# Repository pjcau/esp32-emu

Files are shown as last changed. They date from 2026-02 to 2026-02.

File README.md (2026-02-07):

# ESP32-EMU - DIY Retro Gaming Console

> **[View Interactive 3D Models](https://pjcau.github.io/esp32-emu/)**

Personal project for building a retro gaming emulation console based on ESP32 WROVER, using the ESPlay Retro Emulation firmware.

## Overview

This project documents the build of a handheld console for emulating classic retro gaming systems, based on the ESPlay Micro hardware and the open source firmware by [pebri86](https://github.com/pebri86/esplay-retro-emulation).

## Supported Emulators

- **Nofrendo** - NES/Nintendo Emulator
- **GNUBoy** - GameBoy and GameBoy Color
- **SMSPlusGX** - Sega Master System, Game Gear and Coleco Vision
- **Atari** - Atari Systems
- **PC Engine** - NEC PC Engine/TurboGrafx
- **ZX-Spectrum** - Sinclair ZX Spectrum
- **MSX** - MSX Standard

> Note: Due to the 4MB Flash ROM, only 3 emulators can be preloaded at the same time.

## Additional Features

- In-game menu for all emulators
- Built-in audio player (WAV, MP3, OGG, FLAC)
- ESPlay Launcher with UGUI interface
- Built-in WiFi and Bluetooth 4 BLE

## Technical Specifications (ESPlay Micro)

| Component | Specification |
| --- | --- |
| Processor | ESP32 WROVER dual-core |
| Flash | 4MB built-in |
| PSRAM | 4MB built-in |
| Display | 2.4" ILI9341 TFT Panel |
| Audio DAC | UDA1334A I2S |
| Audio Jack | 3.5mm |
| Storage | microSD slot (SDMMC 1-line) |
| Charger | TP4056 Li-Po built-in |
| USB-Serial | CH340C |
| PCB Dimensions | 100 x 50 mm |
| Expansion Port | I2C |

## Bill of Materials

### 1. Main Board - ESPlay Micro
- **Product**: ESPlay Micro - DIY Console ESP32 WROVER
- **Price**: ~27 EUR
- **Link**: [AliExpress](https://it.aliexpress.com/item/1005010451380752.html)
- Includes: 1x ESPlay Micro, 1x USB Cable, 1x SD Card

### 2. LiPo Battery
- **Product**: 3.7V 5000mAh Lithium Polymer Battery (955565)
- **Price**: ~8 EUR
- **Link**: [AliExpress](https://it.aliexpress.com/item/1005008867815394.html)

### 3. MicroSD Card (optional, for additional ROMs)
- **Product**: SanDisk Ultra Micro SD (32GB/64GB/128GB)
- **Price**: ~1 EUR (32GB)
- **Link**: [AliExpress](https://it.aliexpress.com/item/1005007498167692.html)

### Total Hardware Cost: 35 EUR

## 3D Printed Case

Starting from the original "ESPlay Micro V2 Case" model by PierreGG, I developed a **custom V7 case** generated parametrically via Python + trimesh scripts, optimized for 3D printing.

- **Original model**: [Thingiverse - ESPlay Micro V2 Case](https://www.thingiverse.com/thing:5592683)
- **Custom V7 case**: `model_3d_cover_v1/scripts/build_v7.py` (automatic generation via Docker)
- **Output**: `model_3d_cover_v1/output/v7/` (STL for printing + GLB for viewing)

### V7 Case - Features

| Feature | Detail |
| --- | --- |
| Top shell | Solid top plate with precise cutouts for screen, D-pad (cross), buttons (round) |
| Bottom shell | Optimized depth (19.3mm), battery against inner wall |
| Screws | Countersunk M3 in the bottom, flush with the surface |
| Buttons | 1mm retention flange for snap-fit between board and top body |
| Ports | USB-C, audio jack, SD card slot, shoulder L/R |
| External dimensions | 103.3 x 58.3 x 27.3 mm |

### Closed Assembly

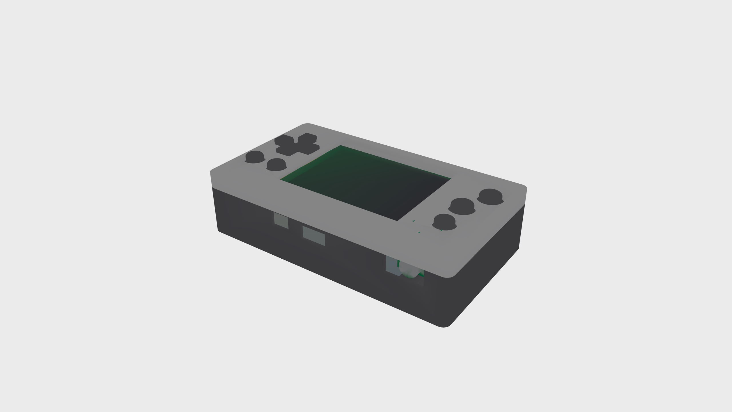
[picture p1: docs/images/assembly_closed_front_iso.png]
Closed assembly - isometric view


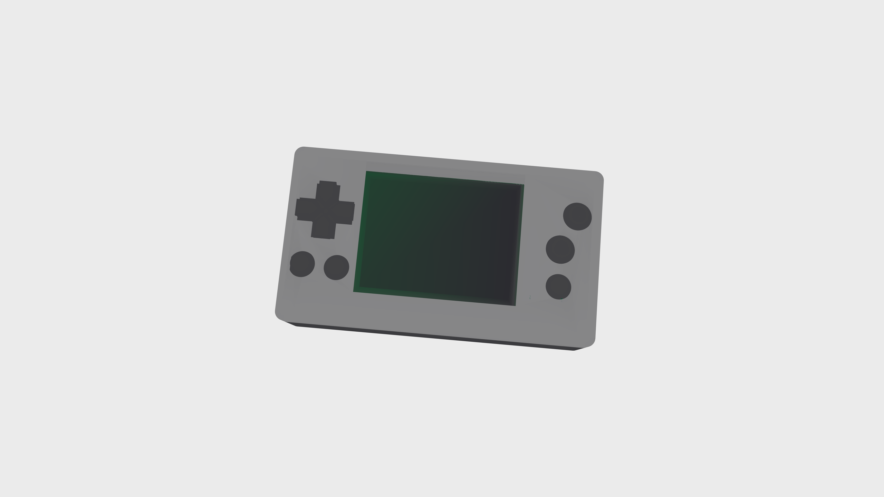
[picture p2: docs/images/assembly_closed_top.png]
Closed assembly - top view


### Exploded Assembly

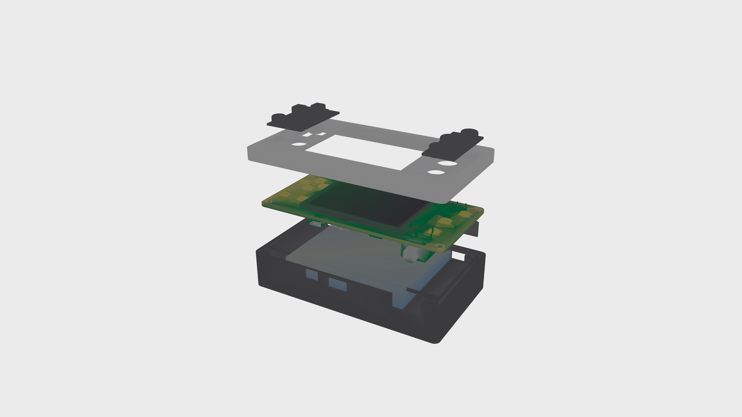
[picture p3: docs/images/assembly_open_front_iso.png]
Exploded assembly - isometric view


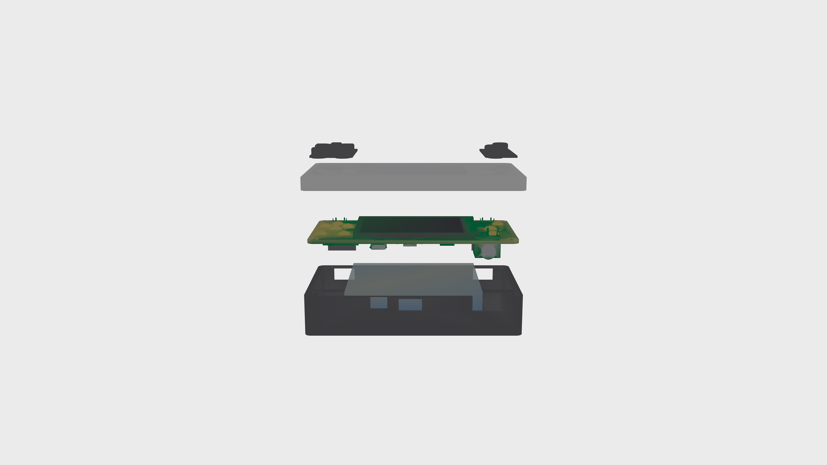
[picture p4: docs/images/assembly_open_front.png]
Exploded assembly - front view


### Top Body - Cutout Detail

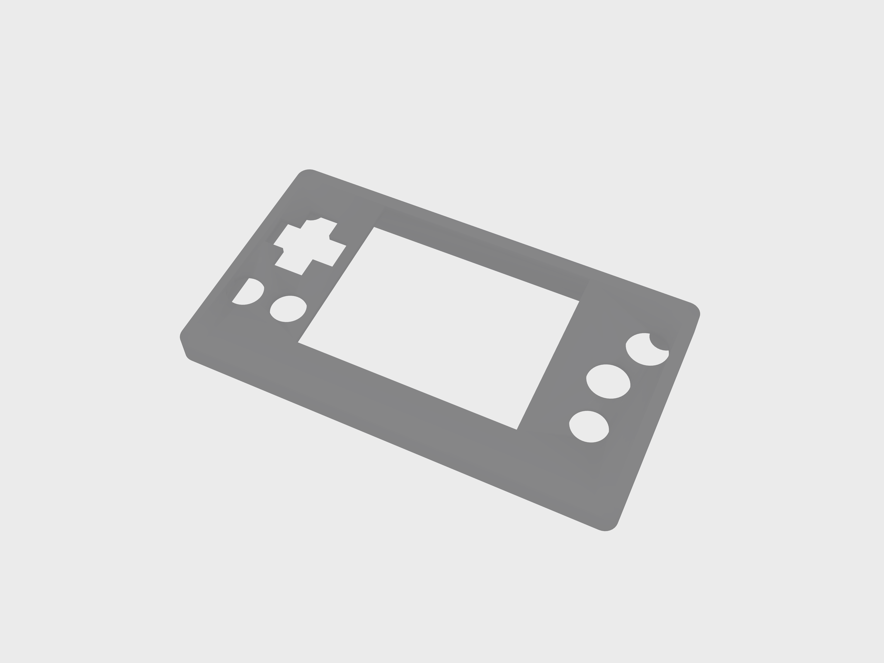
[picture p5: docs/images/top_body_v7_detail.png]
Top body V7 - detail


### How to Generate the Case

```bash
cd model_3d_cover_v1
docker compose run --rm cover-tool /workspace/scripts/build_v7.py
```

STL files for printing are generated in `output/v7/`:
- `top_body_v7.stl` - Top shell
- `bottom_body_v7.stl` - Bottom shell
- `btn_assy_1_v7.stl` - Left button assembly (D-pad + Start/Select)
- `btn_assy_2_v7.stl` - Right button assembly (A/B/X)
- `shoulder_l.stl` / `shoulder_r.stl` - Shoulder buttons

### 3D Printing

I used an **online 3D printing service** for manufacturing the case.

- **Printing cost**: 30 EUR
- Includes all necessary parts for the case

### Required Materials for the Case
- 4x M3 15mm screws
- Screen protector (optional): laser-cut 3mm acrylic (SVG file included)

## Cost Summary

| Item | Cost |
| --- | --- |
| Hardware (ESPlay + Battery + SD)  | 35 EUR |
| 3D Printed Case | 30 EUR |
| **Total Project Cost** | **65 EUR** |

## Resources and Useful Links

| Resource | Link |
| --- | --- |
| ESPlay Firmware | [GitHub - pebri86/esplay-retro-emulation](https://github.com/pebri86/esplay-retro-emulation) |
| Official Documentation | [Makerfabs - ESPlay Micro](https://www.makerfabs.com/esplay-micro.html) |
| 3D Case | [Thingiverse - ESPlay Micro V2 Case](https://www.thingiverse.com/thing:5592683) |

## Firmware Build Instructions

### Requirements
- ESP-IDF v3.3
- FFmpeg installed and in PATH

### Procedure
1. Clone the repository: `git clone https://github.com/pebri86/esplay-retro-emulation.git`
2. Edit `mkrelease.sh` with the correct paths
3. Run `./mkrelease.sh` to generate `esplay-retro-emu.fw`
4. Copy the file to `esplay/firmware/` on the SD card
5. Boot the console while holding the B button (bootloader mode)
6. Flash the firmware from the menu

## Assembly Instructions

1. Solder the LiPo battery to the ESPlay Micro board connectors
2. Insert the microSD card with the ROMs
3. 3D print the case
4. Assemble everything with the M3 screws
5. (Optional) Apply the acrylic screen protector

## SD Card Directory Structure

```
/
├── esplay/
│   └── firmware/
│       └── esplay-retro-emu.fw
├── roms/
│   ├── nes/
│   ├── gb/
│   ├── gbc/
│   ├── sms/
│   └── gg/
└── music/
    └── (WAV, MP3, OGG, FLAC files)
```

## Legal Notes

- The ESPlay firmware is released under the MIT License
- Only use ROMs for games you legally own
- The 3D case is released under the Creative Commons BY 4.0 License

## TODO

- [x] Order components
- [x] 3D print the case
- [ ] Assemble the hardware
- [ ] Flash the firmware
- [ ] Test the emulators
- [ ] Document the process with photos

---

*Project based on the work of [Fuji Pebri](https://github.com/pebri86) and the ESPlay community.*

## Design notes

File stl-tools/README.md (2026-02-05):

# STL Processing Tools

Tools for analyzing and fixing STL files for 3D printing, ensuring minimum wall thickness requirements are met while preserving part alignment for assembly.

## Requirements

- Docker
- Docker Compose

## Quick Start

```bash
cd stl-tools

# Run complete pipeline (recommended)
./run.sh pipeline

# Or run everything including renders and animations
./run.sh all
```

## Features

1. **Wall Thickness Analysis**: Checks all STL files for wall thickness < 1mm
2. **Automatic Fix**: Thickens thin walls while preserving part centers
3. **Assembly Verification**: Ensures parts still fit together after fixes
4. **Render Comparison**: Before/after visual comparisons
5. **Assembly Simulation**: Animated assembly/disassembly views
6. **Hardware Verification**: Checks alignment with PCB, screw holes, etc.

## Commands

| Command | Description |
|---|---|
| `./run.sh analyze` | Analyze STL files only |
| `./run.sh fix` | Fix wall thickness issues |
| `./run.sh verify` | Verify parts fit together |
| `./run.sh render` | Generate render comparisons |
| `./run.sh simulate` | Generate assembly animations |
| `./run.sh hardware` | Verify hardware alignment |
| `./run.sh pipeline` | Run complete pipeline |
| `./run.sh all` | Run everything |
| `./run.sh clean` | Remove output files |
| `./run.sh shell` | Open container shell |

## Output Files

After running the pipeline, check these output files:

```
output/
├── analysis_report.json       # Initial thickness analysis
├── analysis_summary.txt       # Human-readable analysis summary
├── fixed/                     # Fixed STL files
│   ├── frame.stl
│   ├── top_cover.stl
│   └── ...
├── fix_report.json            # Fix operation results
├── verification_report.json   # Assembly fit verification
├── pipeline_report.html       # Complete HTML report
├── renders/                   # Render images
│   ├── render_report.html
│   └── *.png
├── simulation/                # Animation files
│   ├── simulation_viewer.html
│   ├── assembly.gif
│   ├── disassembly.gif
│   └── rotation_*.gif
└── hardware_verification_report.json
```

## Configuration

Environment variables in `docker-compose.yml`:

| Variable | Default | Description |
|---|---|---|
| `MIN_WALL_THICKNESS` | `1.0` | Minimum wall thickness in mm |
| `PRESERVE_CENTERS` | `true` | Keep part centers invariant during fix |
| `FIX_METHOD` | `auto` | Fix method: auto, vertex, shell, pymeshlab |
| `NUM_SAMPLES` | `15000` | Samples for thickness analysis |

## How It Works

### Wall Thickness Analysis
Uses ray casting from surface points inward to measure the distance to the opposite surface. This gives an accurate measurement of wall thickness at thousands of sample points.

### Thickness Fix Algorithm
1. Identifies thin regions (< 1mm)
2. Calculates required offset for each vertex
3. Displaces vertices outward along normals
4. Translates mesh to preserve original centroid
5. Verifies fix meets requirements

### Center Preservation
After any mesh modification, the centroid is calculated and the mesh is translated to match the original centroid position. This ensures parts remain properly aligned in the assembly.

### Assembly Verification
Uses collision detection between all part pairs to ensure no unwanted intersections occur after thickness fixes.

## Input Files

The pipeline expects STL files in:
```
model3d/ESPlay micro v2 case - 5592683/files/
```

Expected files:
- `frame.stl` - Main case frame
- `top_cover.stl` - Front cover
- `back_cover.stl` - Back cover
- `d_Pad.stl` - D-pad
- `A_B.stl` - A/B buttons
- `L_R.stl` - Shoulder buttons
- `start_select.stl` - Start/Select buttons
- `menu.stl` - Menu button
- `power.stl` - Power button

## Troubleshooting

### Rendering fails
The container uses OSMesa for headless rendering. If renders are blank, check:
```bash
./run.sh shell
python -c "import trimesh; print(trimesh.viewer)"
```

### Fix doesn't meet thickness requirement
Try different fix methods:
```bash
# Edit docker-compose.yml
environment:
  - FIX_METHOD=shell  # or 'vertex' or 'pymeshlab'
```

### Parts don't fit after fix
If assembly verification fails, the fix may have been too aggressive. Reduce the offset or use a different method.

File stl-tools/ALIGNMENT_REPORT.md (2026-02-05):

# ESPlay Micro - Alignment Analysis Report

**Data**: 2026-02-04
**Progetto**: ESP32-EMU Console Retro Gaming

---

## 1. Coordinate System Analysis

### STL Case Orientation
Il case STL utilizza un sistema di coordinate dove:
- **X positivo** = lato destro della console
- **X negativo** = lato sinistro della console
- **Y** = INVERTITO rispetto al PCB

### PCB Orientation (Eagle)
- **X positivo** = lato destro (dove sono A/B, Menu)
- **X negativo** = lato sinistro (dove sono D-Pad, Start/Select)
- **Y positivo** = lato superiore (dove sono L/R shoulders)
- **Y negativo** = lato inferiore (USB, Audio)

### Trasformazione Applicata
Y-axis invertito per allineare i sistemi di coordinate.

---

## 2. Button Positions Comparison

| Componente | STL Center (X, Y) | PCB Center (X, Y) | Offset (mm) | Status |
|---|---|---|---|---|
| d_Pad | (-39.1, 5.5) | (-39.1, 8.0) | 2.5 | ✓ OK |
| A_B | (39.4, -3.8) | (41.5, 7.6) | 11.6 | ⚠ Offset |
| start_select | (-39.2, -12.0) | (-39.1, -10.4) | 1.5 | ✓ OK |
| menu | (41.5, 14.0) | (39.0, -10.5) | 24.7 | ⚠ Offset |
| power | (-4.7, -0.6) | (18.6, 10.6) | 25.8 | ⚠ Offset |

### L/R Shoulders (caso speciale)
- STL L_R è un **pezzo singolo** posizionato sul lato destro (X=42.0)
- PCB ha L_BTN (X=-38.6) e R_BTN (X=38.9) separati
- **Nota**: Il pezzo L_R potrebbe necessitare di essere specchiato per il lato sinistro

---

## 3. Layout Console

```
      L_BTN                              R_BTN
   ┌─────────────────────────────────────────────┐
   │                                             │
   │  ┌─────┐                        ┌───┐       │
   │  │D-Pad│        ┌──────┐        │A/B│       │
   │  └─────┘        │ LCD  │        └───┘       │
   │                 │Screen│                    │
   │  ┌──────────┐   └──────┘        ┌────┐      │
   │  │Start/Sel │                   │Menu│      │
   │  └──────────┘                   └────┘      │
   │                                             │
   └─────────────────────────────────────────────┘
           USB              AUDIO
```

---

## 4. Dimensional Compatibility

| Componente | Dimensioni (mm) |
|---|---|
| PCB | 100.0 x 50.0 x 1.6 |
| Top Cover | 110.7 x 55.7 x 10.0 |
| Back Cover | 110.0 x 55.0 x 11.0 |

**Margine Case-PCB**: ~5mm per lato (adeguato per montaggio)

---

## 5. Render Files

I seguenti file sono stati generati in `stl-tools/output/renders/`:

| File | Descrizione |
|---|---|
| assembly_colored.glb | Assembly completo con PCB e case |
| assembly_exploded.glb | Vista esplosa dei componenti |
| pcb_detailed.glb | PCB con marker posizioni bottoni |
| case_only.glb | Solo case senza PCB |
| viewer.html | Viewer 3D interattivo |

### Visualizzazione
```bash
# Avviare server e aprire viewer
python3 -m http.server 8082 --directory stl-tools/output/renders
# Poi aprire: http://localhost:8082/viewer.html
```

---

## 6. Conclusioni

### Compatibilità
- ✓ Dimensioni case compatibili con PCB 100x50mm
- ✓ Posizioni X dei bottoni allineate
- ⚠ Y-axis invertito - compensato nei render

### Note
- Il pezzo L_R è singolo e posizionato a destra; verificare se serve specchiatura
- Gli offset residui sono dovuti a differenze di design tra case Thingiverse e PCB ESPlay

---

*Report generato automaticamente - ESP32-EMU Project*

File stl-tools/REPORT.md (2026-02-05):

# ESPlay Micro - Report Analisi e Fix STL

**Data**: 2026-02-04
**Progetto**: ESP32-EMU Console Retro Gaming

---

## 1. Panoramica

Questo report documenta l'analisi, la correzione e la verifica dei file STL per il case ESPlay Micro V2, inclusa la compatibilità con il PCB originale.

### Obiettivi
1. Verificare che tutti i pezzi STL abbiano spessore minimo >= 1.0mm per la stampa 3D
2. Preservare i centroidi originali (nessun drift)
3. Mantenere dimensioni controllate (minimo aumento)
4. Verificare compatibilità con PCB ESPlay Micro (100x50mm)

---

## 2. File Sorgente

### PCB (da esplay_micro_hardware)
- **Repository**: https://github.com/pebri86/esplay_micro_hardware
- **File**: `new_esplay.brd` (Eagle format)
- **Dimensioni**: 100.0 x 50.0 x 1.6 mm
- **Fori montaggio**: 4 (M3, agli angoli)

### Case STL (da Thingiverse)
- **Sorgente**: ESPlay Micro V2 Case (Thing:5592683)
- **File originali**: 9 pezzi STL
- **Directory**: `model3d/ESPlay micro v2 case - 5592683/files/`

---

## 3. Analisi Spessore Originale

| Pezzo | Dimensioni Originali | Spessore (P5) | Stato |
|---|---|---|---|
| A_B | 8.7 x 21.5 x 4.2 mm | 0.20 mm | ❌ Troppo sottile |
| L_R | 16.0 x 5.0 x 9.0 mm | 0.20 mm | ❌ Troppo sottile |
| d_Pad | 20.8 x 20.8 x 4.2 mm | 0.20 mm | ❌ Troppo sottile |
| menu | 10.6 x 10.6 x 4.2 mm | 0.20 mm | ❌ Troppo sottile |
| power | 15.0 x 2.5 x 5.0 mm | 0.20 mm | ❌ Troppo sottile |
| start_select | 20.6 x 8.8 x 4.2 mm | 0.20 mm | ❌ Troppo sottile |
| frame | 54.6 x 42.2 x 4.5 mm | 0.49 mm | ❌ Troppo sottile |
| top_cover | 110.0 x 55.0 x 9.4 mm | 0.50 mm | ❌ Troppo sottile |
| back_cover | 110.0 x 55.0 x 11.0 mm | 3.30 mm | ✅ OK |

**Problema**: 8 su 9 pezzi hanno spessore < 1.0mm

---

## 4. Metodo di Fix Applicato

### Approccio: Vertex Normal Offset
- Offset dei vertici lungo le normali
- Preservazione del centroide tramite ri-centramento
- Offset differenziato per tipo di pezzo

### Parametri
| Tipo | Offset Applicato |
|---|---|
| Bottoni (A_B, d_Pad, menu, power, start_select, L_R) | 0.6 mm |
| Struttura (frame, top_cover) | 0.35 mm |
| back_cover | 0 mm (già OK) |

---

## 5. Risultati Fix

### Dimensioni Finali

| Pezzo | Originale | Fixed | Incremento |
|---|---|---|---|
| A_B | 8.7 x 21.5 x 4.2 | 9.8 x 22.4 x 5.4 | +1.1 x 0.9 x 1.2 |
| L_R | 16.0 x 5.0 x 9.0 | 16.9 x 6.2 x 10.1 | +0.9 x 1.2 x 1.1 |
| d_Pad | 20.8 x 20.8 x 4.2 | 21.7 x 21.8 x 5.4 | +0.9 x 1.0 x 1.2 |
| menu | 10.6 x 10.6 x 4.2 | 11.6 x 11.6 x 5.4 | +1.0 x 1.0 x 1.2 |
| power | 15.0 x 2.5 x 5.0 | 16.1 x 3.5 x 6.1 | +1.1 x 1.0 x 1.1 |
| start_select | 20.6 x 8.8 x 4.2 | 21.6 x 9.9 x 5.4 | +1.0 x 1.1 x 1.2 |
| frame | 54.6 x 42.2 x 4.5 | 55.0 x 42.6 x 5.0 | +0.4 x 0.4 x 0.5 |
| top_cover | 110.0 x 55.0 x 9.4 | 110.7 x 55.7 x 10.0 | +0.7 x 0.7 x 0.6 |
| back_cover | 110.0 x 55.0 x 11.0 | 110.0 x 55.0 x 11.0 | 0 |

### Spessore Finale

| Pezzo | Spessore (P5) | Stato |
|---|---|---|
| A_B | 1.05 mm | ✅ OK |
| L_R | 1.03 mm | ✅ OK |
| d_Pad | 1.05 mm | ✅ OK |
| menu | 1.01 mm | ✅ OK |
| power | 1.04 mm | ✅ OK |
| start_select | 1.05 mm | ✅ OK |
| frame | 1.06 mm | ✅ OK |
| top_cover | 1.08 mm | ✅ OK |
| back_cover | 3.30 mm | ✅ OK |

### Centroidi

| Pezzo | Drift | Stato |
|---|---|---|
| Tutti | 0.0000 mm | ✅ Preservati |

---

## 6. Compatibilità PCB

### Dimensioni
| Componente | Dimensioni |
|---|---|
| PCB ESPlay Micro | 100.0 x 50.0 mm |
| Top Cover (interno stim.) | ~105 x 50 mm |
| Margine | ~2.5 mm per lato |

**Risultato**: ✅ PCB compatibile con case

### Posizioni Componenti PCB

| Componente | Posizione (centrata) | Colore nel Render |
|---|---|---|
| LCD Display | (1.6, 1.0) | Blu scuro |
| D-Pad | (-39.1, 8.0) | Rosso |
| A/B Buttons | (41.5, 7.6) | Verde |
| Start/Select | (-39.1, -10.4) | Arancione |
| Menu | (39.0, -10.5) | Magenta |
| L Button | (-38.6, 20.7) | Giallo |
| R Button | (38.9, 20.7) | Giallo |
| Power | (18.6, 10.6) | Ciano |

---

## 7. File Generati

### STL Fixati (pronti per stampa)
```
stl-tools/output/fixed_v2/
├── A_B.stl
├── L_R.stl
├── back_cover.stl
├── d_Pad.stl
├── frame.stl
├── menu.stl
├── power.stl
├── start_select.stl
└── top_cover.stl
```

### Modelli PCB
```
pcb/
├── new_esplay.brd          # File Eagle originale
├── esplay_micro_pcb.stl    # PCB semplice
├── esplay_micro_pcb_3d.stl # PCB con pulsanti 3D
└── pcb_component_positions.json
```

### Render e Visualizzazione
```
stl-tools/output/renders/
├── viewer.html             # Viewer 3D interattivo
├── assembly_colored.glb    # Assembly completo
├── assembly_exploded.glb   # Vista esplosa
├── pcb_detailed.glb        # PCB con marker
└── case_only.glb           # Solo case
```

---

## 8. Legenda Colori

| Colore | Componente |
|---|---|
| 🔴 Rosso | D-Pad |
| 🟢 Verde | A/B Buttons |
| 🟠 Arancione | Start/Select |
| 🟣 Magenta | Menu |
| 🟡 Giallo | L/R Shoulders |
| 🔵 Ciano | Power |
| 🔷 Steel Blue | Top Cover |
| 🔹 Cornflower Blue | Back Cover |
| ⬜ Grigio | Frame |
| 🌲 Verde Scuro | PCB |

---

## 9. Come Visualizzare

### Viewer HTML Interattivo
```bash
open stl-tools/output/renders/viewer.html
```

Funzionalità:
- Rotazione: trascinare con mouse
- Zoom: scroll
- 4 viste: assemblato, esploso, PCB, solo case

### File GLB
Apribili con:
- macOS: Quick Look (spacebar nel Finder)
- Windows: 3D Viewer
- Online: https://gltf-viewer.donmccurdy.com/

---

## 10. Conclusioni

### ✅ Obiettivi Raggiunti

1. **Spessore >= 1.0mm**: Tutti i 9 pezzi soddisfano il requisito
2. **Centroidi preservati**: 0.000mm drift per tutti
3. **Dimensioni controllate**: Aumento max ~1.2mm
4. **Compatibilità PCB**: Case compatibile con PCB 100x50mm

### Note

- I file STL originali del case hanno un sistema di coordinate leggermente diverso dal PCB Eagle
- Alcuni pulsanti mostrano offset di posizione nel confronto diretto, ma questo è nel design originale del case, non causato dal fix
- I pezzi fixati sono pronti per la stampa 3D FDM

---

## 11. Prossimi Passi

- [ ] Stampare i pezzi fixati
- [ ] Verificare fit fisico con PCB reale
- [ ] Assemblare console completa
- [ ] Documentare con foto

---

*Report generato automaticamente - ESP32-EMU Project*

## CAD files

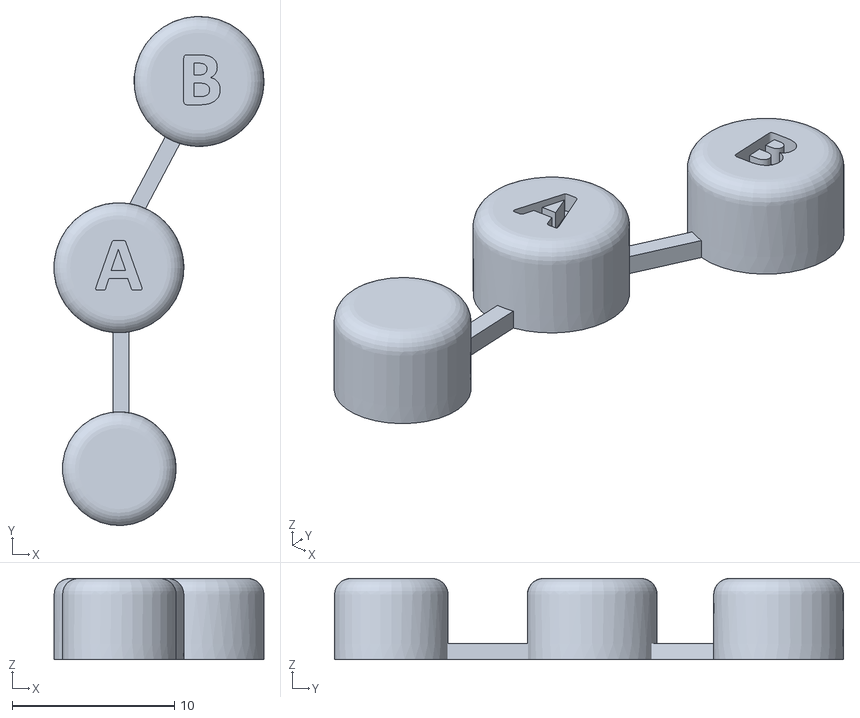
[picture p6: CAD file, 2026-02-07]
model_3d_cover_v1/original/btn_assy_2.stl
12.9 x 31.3 x 5.00

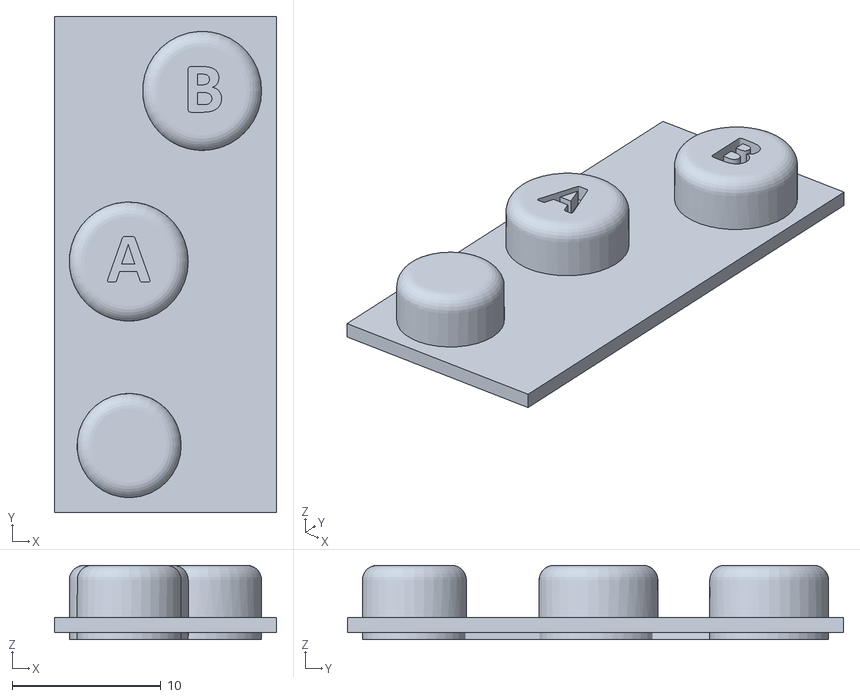
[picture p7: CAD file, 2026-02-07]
model_3d_cover_v1/output/v7/btn_assy_2_v7.stl
14.9 x 33.3 x 5.00

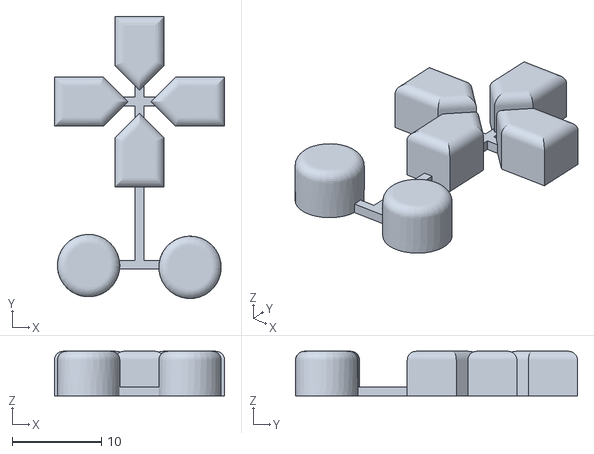
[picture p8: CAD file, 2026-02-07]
model_3d_cover_v1/original/btn_assy_1.stl
19.1 x 31.6 x 5.00

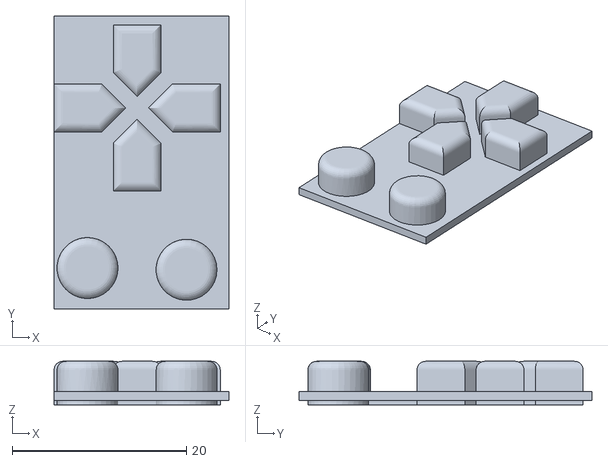
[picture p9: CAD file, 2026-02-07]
model_3d_cover_v1/output/v7/btn_assy_1_v7.stl
20.1 x 33.6 x 5.00

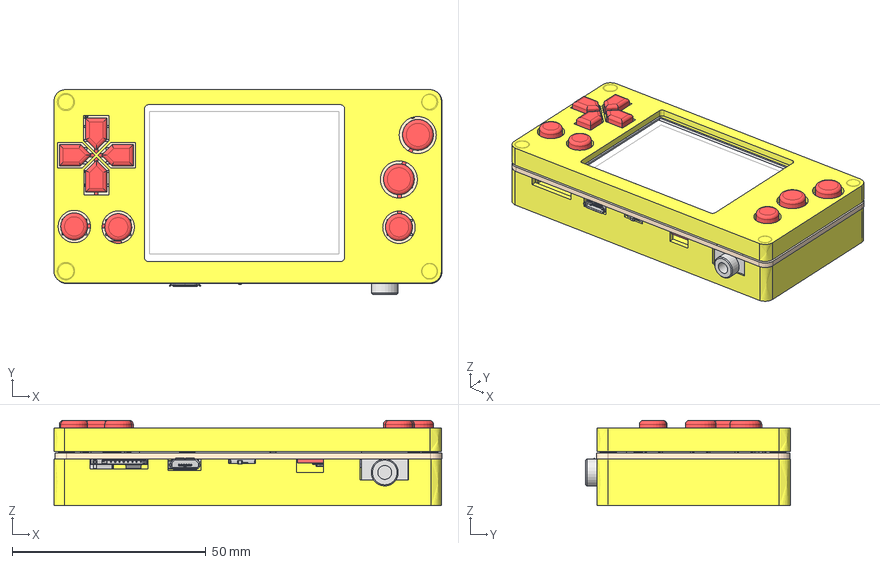
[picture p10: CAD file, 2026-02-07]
model_3d_cover_v1/original/case_design.FCStd
100.2 x 52.9 x 22.0 mm
left_btn
front
right_btn
Board
SMT-JUMPER_2_NC_TRACE_NO-SILK
1X02M
XCVR_ESP32-WROVER-I
MICROBUILDER_SSOP16_4.4MM
pcm12smtr_body
pcm12smtr_shield
pcm12smtr_pins
pcm12smtr_slider
ILI9341-2.4
\X\CB\X\F5\X\B7\X\C5\X\B1\X\C8\X\C0\X\FD1
\X\CD\X\B9\X\CC\X\A8-\X\C0\X\AD\X\C9\X\EC1
\X\C1\X\AC\X\BD\X\D3\X\D6\X\D8\X\D7\X\E91
TACTILE_SWITCH_SMD_4.6X2.8MM
TACTILE_SWITCH_SMD_5.2MM
TACTILE_SWITCH_SMD_5.2MM001
TACTILE_SWITCH_SMD_5.2MM002
TACTILE_SWITCH_SMD_5.2MM003
TACTILE_SWITCH_SMD_5.2MM004
TACTILE_SWITCH_SMD_5.2MM005
TACTILE_SWITCH_SMD_5.2MM006
TACTILE_SWITCH_SMD_5.2MM007
TACTILE_SWITCH_SMD_5.2MM008
MICROBUILDER_MOUNTINGHOLE_3.0_PLATEDTHIN
MICROBUILDER_MOUNTINGHOLE_3.0_PLATEDTHIN001
MICROBUILDER_MOUNTINGHOLE_3.0_PLATEDTHIN002
MICROBUILDER_MOUNTINGHOLE_3.0_PLATEDTHIN003
TACTILE_SWITCH_PTH_RIGHT_ANGLE_KIT
TACTILE_SWITCH_PTH_RIGHT_ANGLE_KIT001
SO16
ESD0402
ESD0403
ESD0404
SMA-DIODE
JST-2-SMD
SOT23-3
SOT23-004
SOT23-005
SOT23-006
SO016
SOT23-5
EIA3528
EIA3529
EIA3530
EIA3531
AUDIO-JACK
USB_LOGO
HEADPHONE_LOGO
SOT95P280X100-5N
LED-0603
CRYSTAL-SMD-5X3.2-4PAD
USB-B-MICRO-SMD
OSHW-LOGO-M
SOP-16
PAD.03X.03
PAD.03X.004
PAD.03X.005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

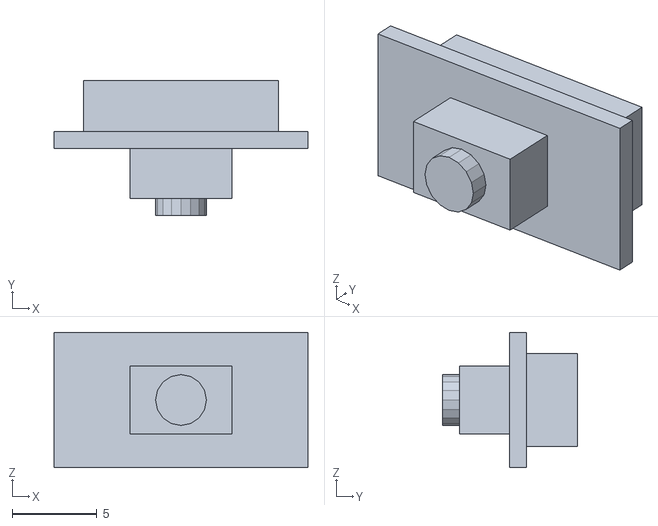
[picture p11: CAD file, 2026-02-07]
model_3d_cover_v1/output/v7/shoulder_l.stl
15.0 x 7.95 x 8.00

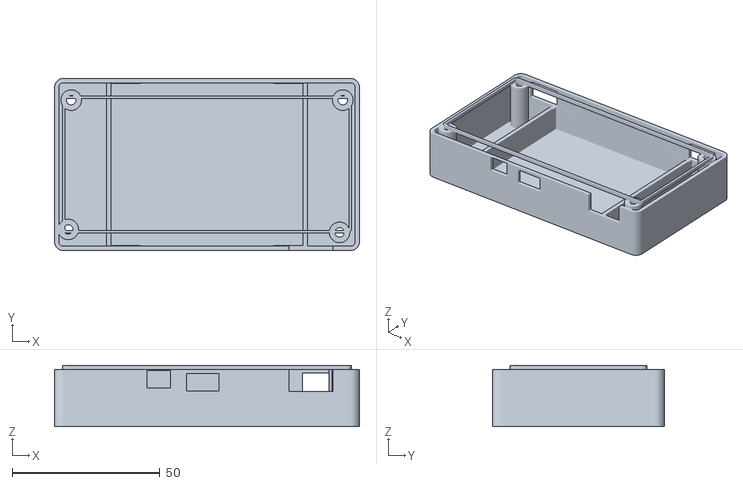
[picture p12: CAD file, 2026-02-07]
model_3d_cover_v1/output/v7/bottom_body_v7.stl
103.3 x 58.3 x 20.8

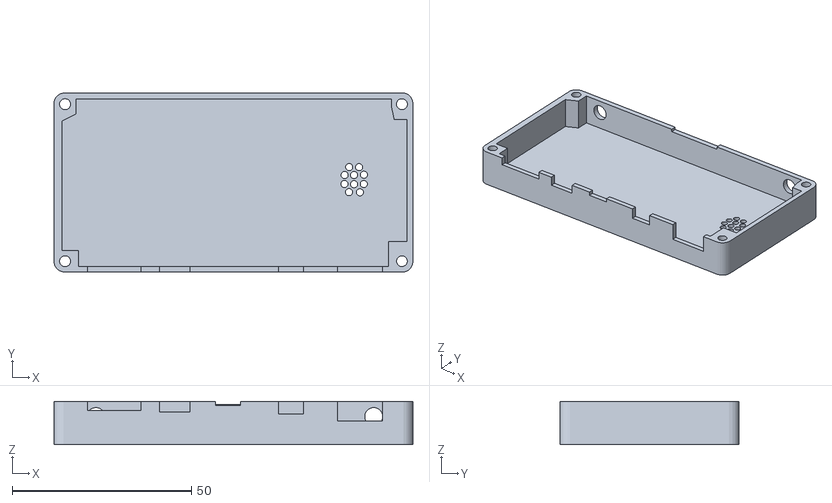
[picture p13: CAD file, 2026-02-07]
model_3d_cover_v1/original/bottom_body.stl
100.0 x 49.9 x 12.0

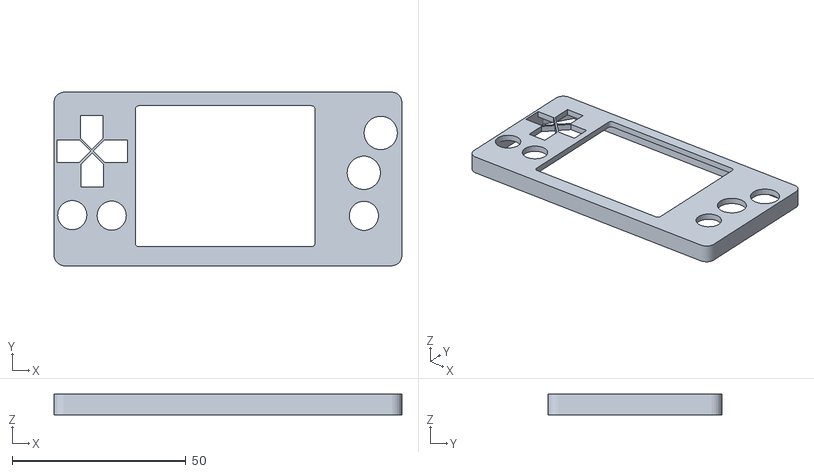
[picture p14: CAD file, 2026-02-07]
model_3d_cover_v1/original/top_body.stl
100.1 x 49.9 x 6.00

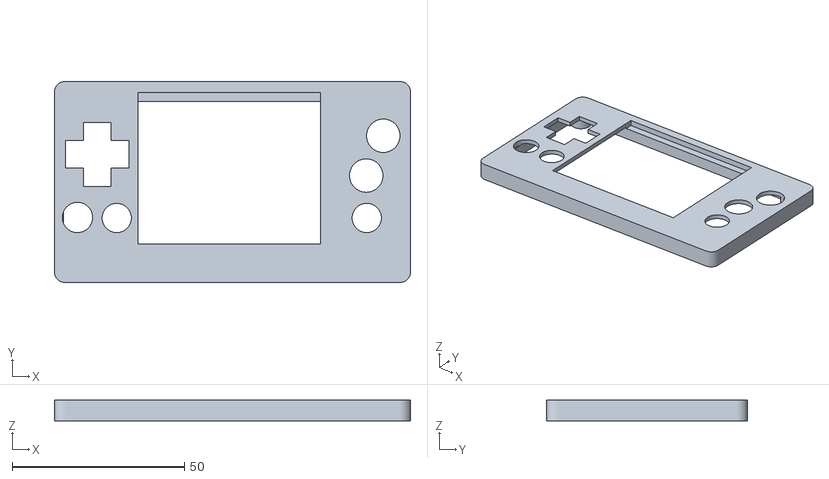
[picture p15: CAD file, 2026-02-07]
model_3d_cover_v1/output/v7/top_body_v7.stl
103.3 x 58.3 x 6.00

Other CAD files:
model_3d_cover_v1/output/v7/shoulder_r.stl

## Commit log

2026-02-03 Initial commit: ESP32-EMU project documentation
    Add comprehensive README with:
    - Project overview and supported emulators
    - Hardware specifications for ESPlay Micro
    - Component list with AliExpress links
    - 3D case link from Thingiverse
    - Firmware build instructions
    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
2026-02-03 Update README: add costs and 3D printing info
    - Add 3D files zip reference
    - Add online 3D printing service cost (30 EUR)
    - Update hardware cost to actual spent (35 EUR)
    - Add total project cost summary table (65 EUR)
2026-02-03 Add 3D model files for ESPlay Micro V2 case
    - Add ESPlay micro v2 case zip from Thingiverse
2026-02-03 Update README: fix 3D files path and mark completed tasks
    - Update 3D files link to model3d/ folder
    - Mark 'Ordinare i componenti' as completed
    - Mark 'Stampare il case 3D' as completed
2026-02-05 Add STL processing pipeline, PCB alignment tools, and print-ready files
    - Add ESPlay Micro PCB files (Eagle .brd/.sch) and component positions
    - Create STL analysis and wall thickness fixing pipeline (>= 1mm)
    - Add scripts for PCB-to-case alignment verification
    - Generate print-ready STL files with correct positioning:
    - Buttons aligned with top_cover holes
    - L/R shoulders at back_cover edge (mirrored L from R)
    - Frame positioned as front bezel
    - Include 3D renders (GLB) and interactive HTML viewer
    - Add comprehensive alignment and fix reports
    [A_B.stl, L.stl, L_R.stl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]
2026-02-05 Add PCB 3D model generator v1 with TOP/BOTTOM layer detection
    - Parse Eagle .brd file for component positions and rotations
    - Detect component layer from rotation prefix ('M' = BOTTOM)
    - Generate 3D model with components on correct PCB side:
    - TOP: LCD, buttons (S2-S9, S11), LED, mounting holes
    - BOTTOM: ESP32, SD card, USB, audio jack, ICs, L/R shoulders
    - Export GLB and STL formats with interactive HTML viewer
    - Docker setup for KiCad/FreeCAD environment
    [esplay_micro_pcb.stl]
2026-02-05 Add ESPlay Micro V2 case STL files and analysis reports
    - Original STL files from Thingiverse (ESPlay micro v2 case - 5592683)
    - FIX_REPORT.md documenting button alignment issues and fixes needed
    - STL analysis reports: fit checks, alignment, PCB positioning
    [A_B.stl, L_R.stl, back_cover.stl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]
2026-02-07 added the data models and rendering
    [A_B.stl, L_R.stl, back_cover.stl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]
2026-02-07 Upgrade rendering to pyrender/EGL with 2K supersampled images
    Replace matplotlib-based renderer with pyrender + EGL offscreen rendering.
    Images are now rendered at 5120x2880 with 2x Lanczos downsampling for
    antialiasing. Add 3D viewer (index.html + GLB models) and remove
    stl-tools/output (now gitignored).
    [A_B.stl, L.stl, L_R.stl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]
